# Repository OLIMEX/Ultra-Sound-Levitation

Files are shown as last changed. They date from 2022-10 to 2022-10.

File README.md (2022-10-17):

# Ultra-Sound-Levitation
Ultra Sound Levitation board with two speakers and potentiometer

Product page: https://www.olimex.com/Products/Soldering-Kits/Ultra-Sound-Levitation/open-source-hardware

## License
* Hardware is released under CERN Open Hardware Licence Version 2 - Strongly Reciprocal https://spdx.org/licenses/CERN-OHL-S-2.0.html
* Software is released under GPL3 License
* Documentation is released under CC BY-SA 4.0 https://creativecommons.org/licenses/by-sa/4.0/

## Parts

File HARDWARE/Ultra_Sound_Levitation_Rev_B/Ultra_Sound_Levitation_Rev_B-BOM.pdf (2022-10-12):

Ultra_Sound_Levitation | 10/10/2022
Quantity | Designation | Package | Designator
2 | 22R/0.25W | R_0.25W_PTH | R3,R4
2 | 1.5k/0.25W | R_0.25W_PTH | R1,R2
2 | 100nF/25V/2010 | C2010 | C2,C8
6 | 4.7uF/50V | CPOL-RM2mm_5x11mm_PTH | C1,C3,C4,C5,C6,C7
2 | 1N4148/DO35 | DO35_1K_2A | D1,D2
1 | LED/3mm/Green | LED-3mm-PTH-KA | PWR_LED1
1 | TRIM PIHER PT10LV 10K+KNOB | TRIM_PIHER_PT10LV | TR1
1 | ATtiny85-20PU+(DIL-8) | PDIP-8 | U1
1 | MAX232EN+(DIL-16) | PDIP-16 | U2
1 | T1101GP(6x3x4.3mm) | T1101_GP-6x3x4.3 | RST1
2 | BUZZER – TCT40-16T | SPEAKER_ULTRASONIC | SPK1,SPK2
1 | USB-B(USB-SRWH-4B-LF) | USB-B(USB-SRWH-4B-LF) | USB_DEV1

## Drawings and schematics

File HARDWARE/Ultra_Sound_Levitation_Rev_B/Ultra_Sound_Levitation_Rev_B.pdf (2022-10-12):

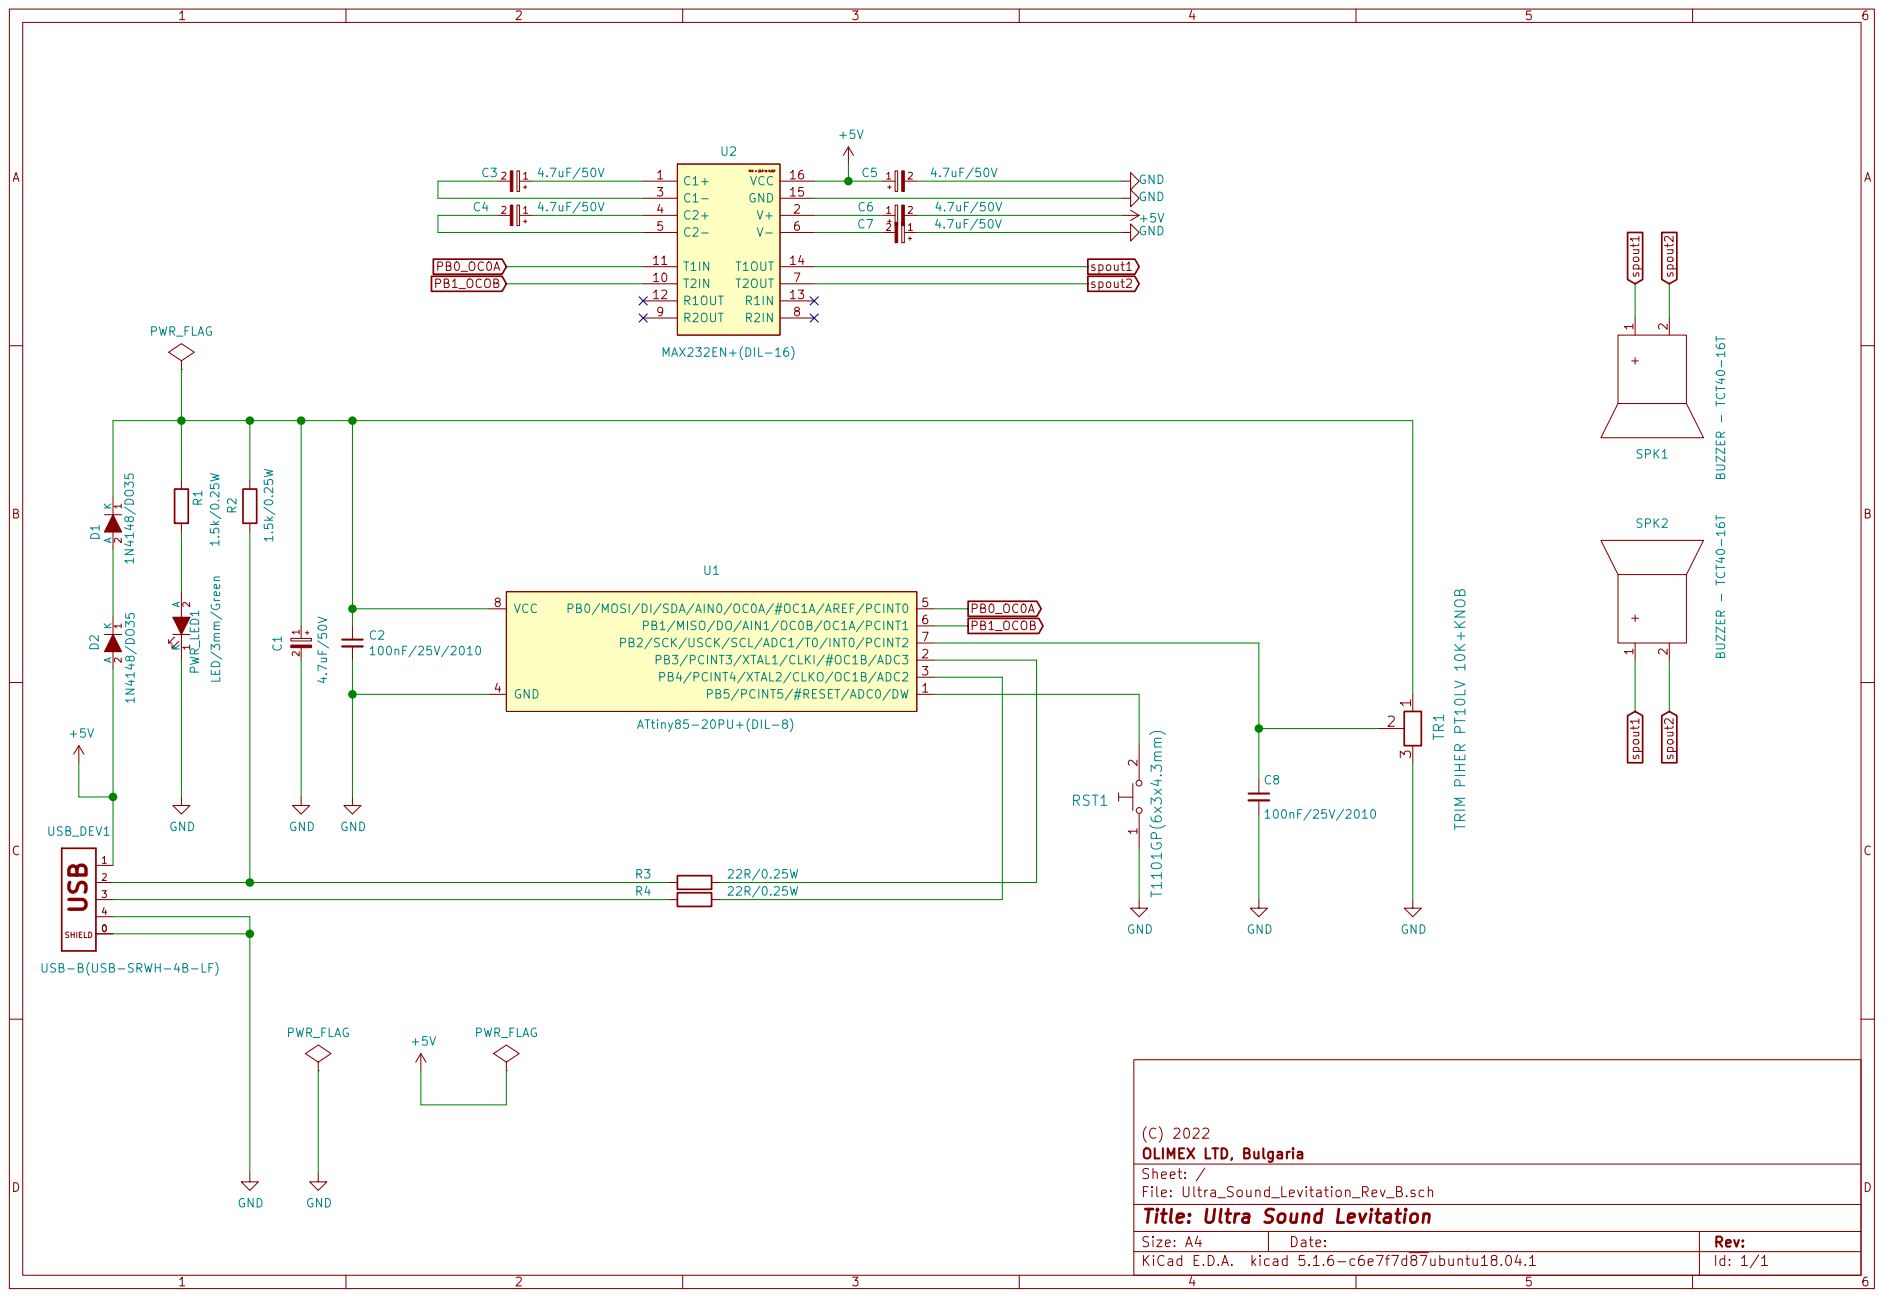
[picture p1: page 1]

4 USB_DEV1 USB-B(USB-SRWH-4B-LF)
SHIELDUSB

File: Ultra_Sound_Levitation_Rev_B.sch Sheet: / OLIMEX LTD, Bulgaria

Id: 1/1 Title: Ultra Sound Levitation

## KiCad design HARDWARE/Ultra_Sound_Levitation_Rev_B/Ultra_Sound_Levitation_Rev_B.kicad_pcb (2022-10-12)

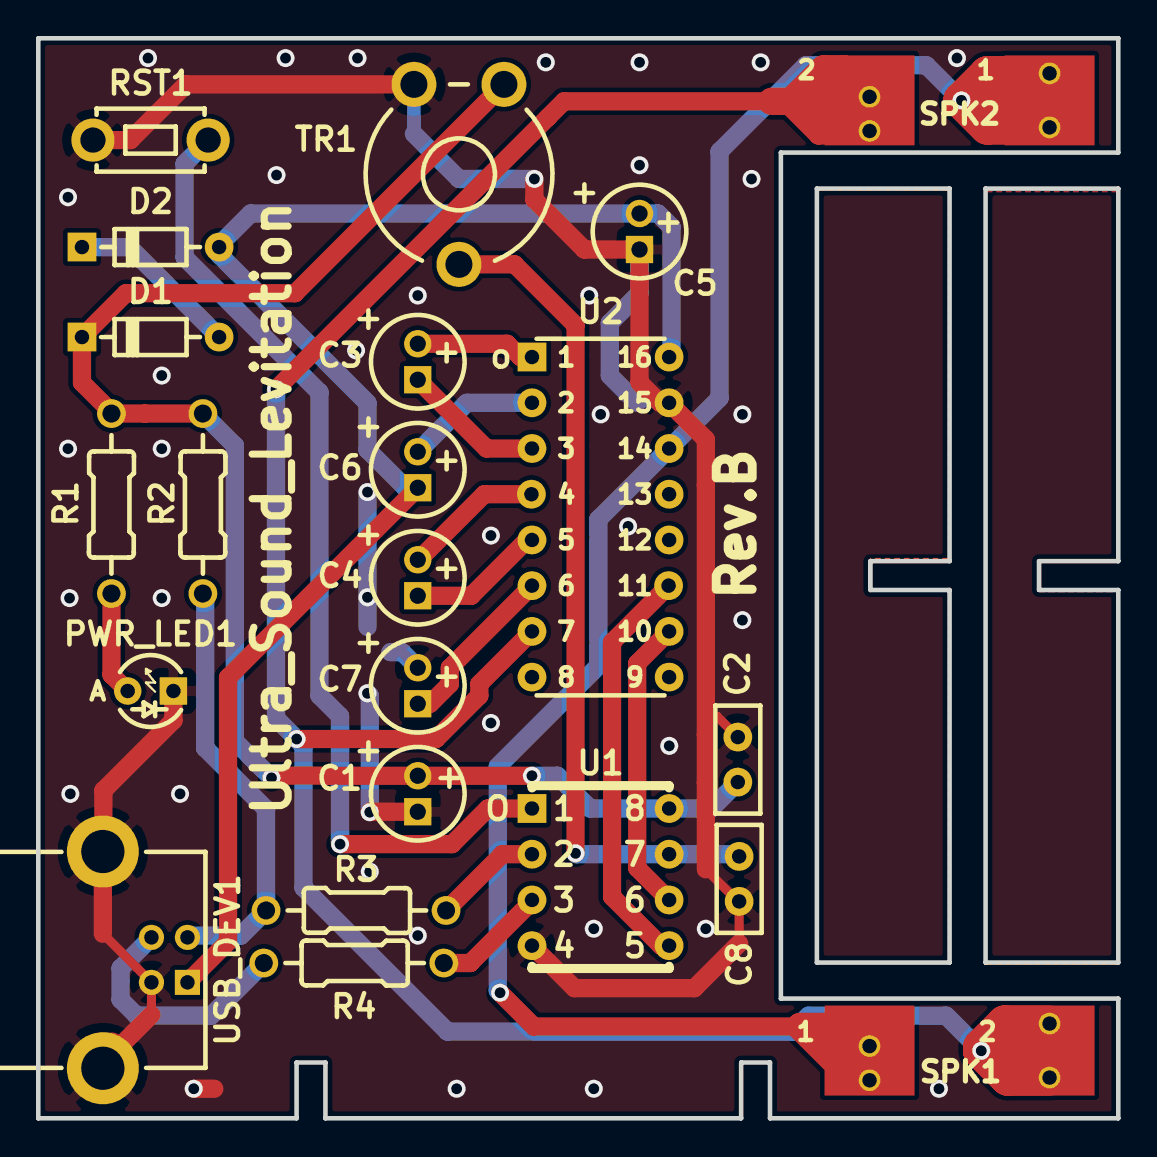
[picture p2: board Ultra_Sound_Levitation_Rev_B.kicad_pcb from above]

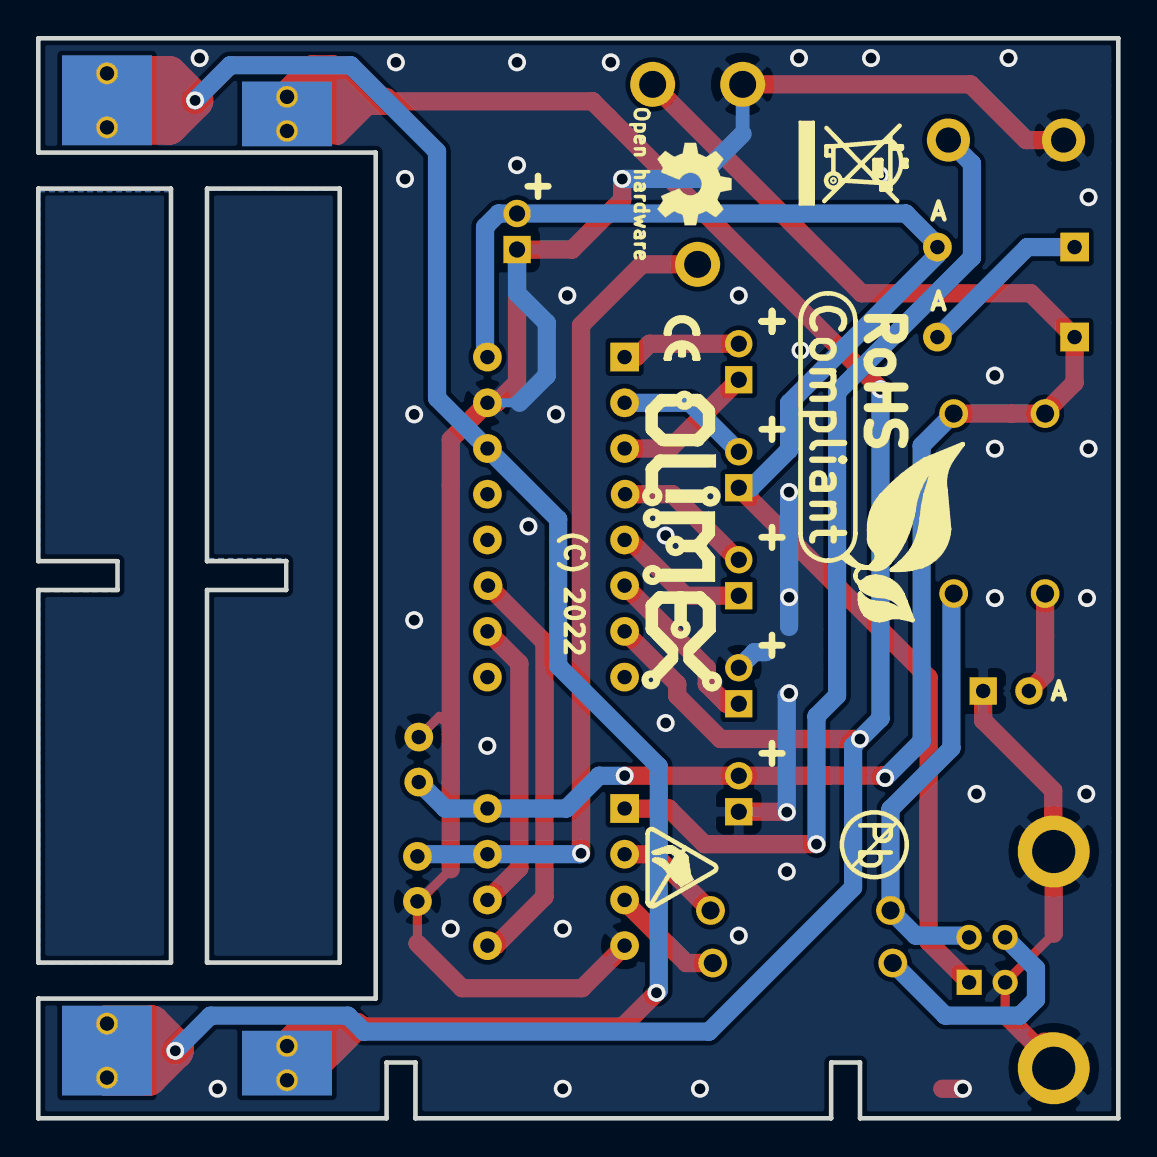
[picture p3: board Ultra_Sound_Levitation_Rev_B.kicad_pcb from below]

Board: 2 copper layers, 60.0 x 60.0 mm, 29 parts (7 on the bottom side), 21 nets.

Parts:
C1, C3, C4, C5, C6, C7: 4.7uF/50V; CPOL-RM2mm_5x11mm_PTH
C2, C8: 100nF/25V/2010; C2010
D1, D2: 1N4148/DO35; DO35_1K_2A
Logo_OLIMEX_TB: Logo_OLIMEX_TB
PWR_LED1: LED/3mm/Green; LED-3mm-PTH-KA
R1, R2: 1.5k/0.25W; R_0.25W_PTH
R3, R4: 22R/0.25W; R_0.25W_PTH
RST1: T1101GP(6x3x4.3mm); T1101_GP-6x3x4.3
SPK1, SPK2: ULTRASONIC?; SPEAKER_ULTRASONIC
Sign_Antistatic_Small: Sign_Antistatic; Sign_Antistatic_4.5mmX2.8mm
Sign_CE_Small: CE_Sign_Small
Sign_OSHW_7.3x6.0mm: Sign_OSHW_7.3x6.0mm; Sign_OSHW_7.3x6.0mmn
Sign_PB-Free: Sign_PB-Free
Sign_RecycleBin_1: Sign_RecycleBin_1
Sign_RoHS_1: Sign_RoHS_1
TR1: TRIM PIHER PT10LV 10K+KNOB; TRIM_PIHER_PT10LV
U1: ATtiny85-20PU+(DIL-8); PDIP-8
U2: MAX232EN+(DIL-16); PDIP-16
USB_DEV1: USB-B(USB-SRWH-4B-LF)

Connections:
+5V: C5.1, C6.2, D2.2, U2.16, USB_DEV1.1
GND: C1.2, C2.2, C5.2, C7.1, C8.2, PWR_LED1.1, RST1.1, TR1.3, U1.4, U2.15, USB_DEV1.0, USB_DEV1.4
unnamed: C1.1, C2.1, D1.1, R1.1, R2.1, TR1.1, U1.8
unnamed: C3.1, U2.1
unnamed: C3.2, U2.3
unnamed: C4.1, U2.4
unnamed: C4.2, U2.5
unnamed: C6.1, U2.2
unnamed: C7.2, U2.6
unnamed: C8.1, TR1.2, U1.7
unnamed: D1.2, D2.1
unnamed: PWR_LED1.2, R1.2
unnamed: R2.2, R3.1, USB_DEV1.2
unnamed: R3.2, U1.2
unnamed: R4.1, USB_DEV1.3
unnamed: R4.2, U1.3
unnamed: RST1.2, U1.1
PB0_OC0A: U1.5, U2.11
PB1_OCOB: U1.6, U2.10
spout1: SPK1.1, SPK2.1, U2.14
spout2: SPK1.2, SPK2.2, U2.7

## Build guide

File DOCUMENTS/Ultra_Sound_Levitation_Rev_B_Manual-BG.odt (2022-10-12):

Ultra Sound Levitation асемблиране

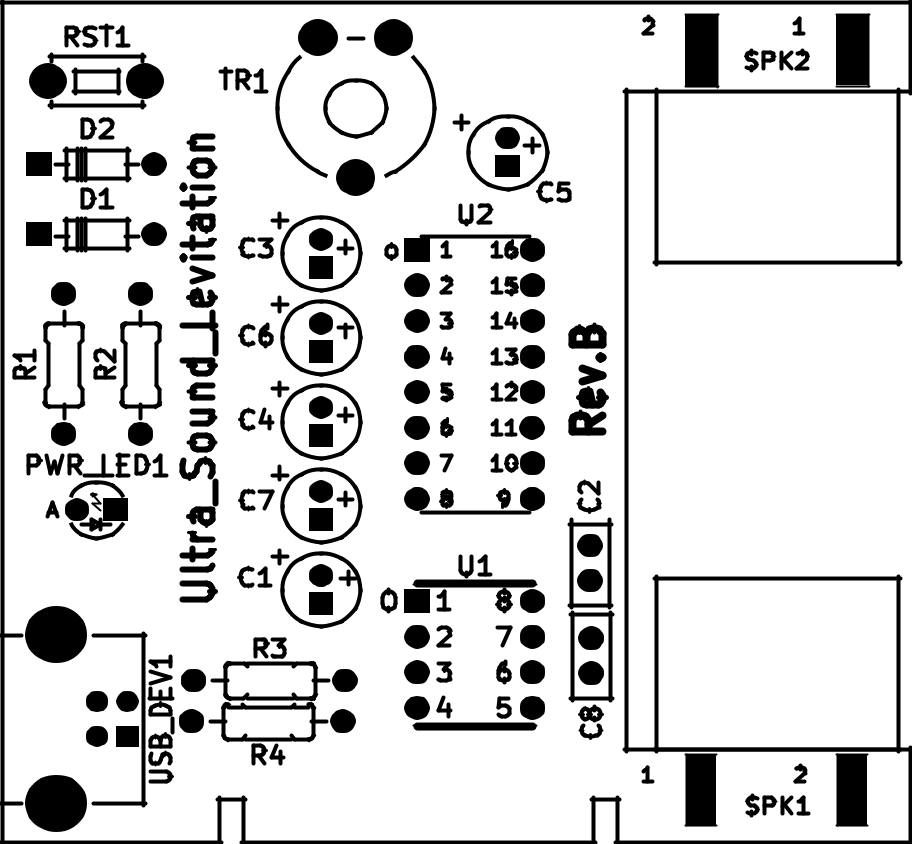
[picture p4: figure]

Qty | Designation | Package | Position
2 | Съпротивление – 22R/0.25W | R_0.25W_PTH | R3, R4
| червено, червено, черно,
| златно
2 | Съпротивление – 1.5k/0.25W | R_0.25W_PTH | R1, R2
| кафяво, зелено, червено,
| златно
2 | Кондензатор- 100nF/25V/2010 | C2010 | C2,C8
6 | Кондензатор – 4.7uF/50V | CPOL- | C1, C3, C4, C5, C6, C7
| | RM2mm_5x11mm_PTH
2 | Диод – 1N4148/DO35 | DO35_1K_2A | D1, D2
1 | Светодиод – 3mm – Зелен | LED-3mm-PTH-KA | PWR_LED1
1 | Потенциометър – PIHER PT10LV | TRIM_PIHER_PT10LV | TR1
| 10K+копче
1 | ATtiny85-20PU | PDIP-8 | U1
1 | MAX232EN | PDIP-16 | U2
1 | Бутон- T1101GP | T1101_GP-6x3x4.3 | RST1
2 | Говорител - TCT40-16T | SPEAKER_ULTRASONIC | SPK1, SPK2
1 | USB-B | USB-B(USB-SRWH-4B-LF) | USB_DEV1

Забележка: компонентите с жълт фон имат поляритет. Забележка: по-дългото краче на PWR_LED1 e анод(плюс)

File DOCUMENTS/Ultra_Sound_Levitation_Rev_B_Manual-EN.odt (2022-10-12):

Ultra Sound Levitation Assembly


Qty | Designation | Package | Position
2 | Resistor – 22R/0.25W | R_0.25W_PTH | R3, R4
| red, red, black,
| gold
2 | Resistor – 1.5k/0.25W | R_0.25W_PTH | R1, R2
| brown, green, red,
| gold
2 | Capacitor- 100nF/25V/2010 | C2010 | C2,C8
6 | Capacitor – 4.7uF/50V | CPOL- | C1, C3, C4, C5, C6, C7
| | RM2mm_5x11mm_PTH
2 | Diode – 1N4148/DO35 | DO35_1K_2A | D1, D2
1 | LED – 3mm – Green | LED-3mm-PTH-KA | PWR_LED1
1 | TRIMMER – PIHER PT10LV | TRIM_PIHER_PT10LV | TR1
| 10K+KNOB
1 | ATtiny85-20PU | PDIP-8 | U1
1 | MAX232EN | PDIP-16 | U2
1 | Button- T1101GP | T1101_GP-6x3x4.3 | RST1
2 | BUZZER - TCT40-16T | SPEAKER_ULTRASONIC | SPK1, SPK2
1 | USB-B | USB-B(USB-SRWH-4B-LF) | USB_DEV1

Remark 1: Yellow background components have POLARITY! Remark 2: The longer leg of PWR_LED1 is Anode(positive)

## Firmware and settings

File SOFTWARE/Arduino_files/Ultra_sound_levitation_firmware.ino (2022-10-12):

// Ultra Sound Levitation soldering kit program

void setup() {
  DDRB = 0b00000011;  // D0 D1  to be outputs
  PORTB = 0b00000010;

//  Initialize Timer1
  noInterrupts();     // Disable interrupts

  TCCR1 = 0b11000001; //CTC TOGGLE NO PRESCALER
  GTCCR = 0;
  TCNT1 = 0;
  OCR1C = 204;        // Set compare register (40kHz full wave)
  TIMSK = 0b01000000; // Enable OCIE1A compare timer interrupt
  
  interrupts();       // Enable interrupts
}

ISR(TIMER1_COMPA_vect) {
  PORTB ^= 0b00000011; // Send the value of TP to the outputs
}

void loop() { 
  OCR1C=map(analogRead(A1), 0, 960, 179, 227);
}

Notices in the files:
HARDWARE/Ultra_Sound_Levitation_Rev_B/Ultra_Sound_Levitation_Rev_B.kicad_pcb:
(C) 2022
